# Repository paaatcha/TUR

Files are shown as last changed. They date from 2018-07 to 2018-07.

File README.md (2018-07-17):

# University Robotic Tournament

In this repository, you can find the codes and files of the [UFES robotic team](http://www.erus.ufes.br/) developed to the III University Robotic Tournament (TUR, in Portuguese), at Federal University of Uberlândia, Brazil. This project was developed by a team composed by me, Guilherme Artém and Vanderlei Vieira.

The tournament's rules are described in [rules.pd](https://github.com/paaatcha/TUR/blob/master/rules.pdf). In brief, the competition was a robot race in which the track race had a line that the robot must follow. In addition, there were extra challenges such as slopes, dark parts, crossroads, dangers turns, etc. The robot needed to be **autonomous** and complete the track race as fast as possible.

The robot structure was developed using the 3D software [openScad](http://www.openscad.org/). Next, this structure was printed in a 3D printer and used as the robot "body".

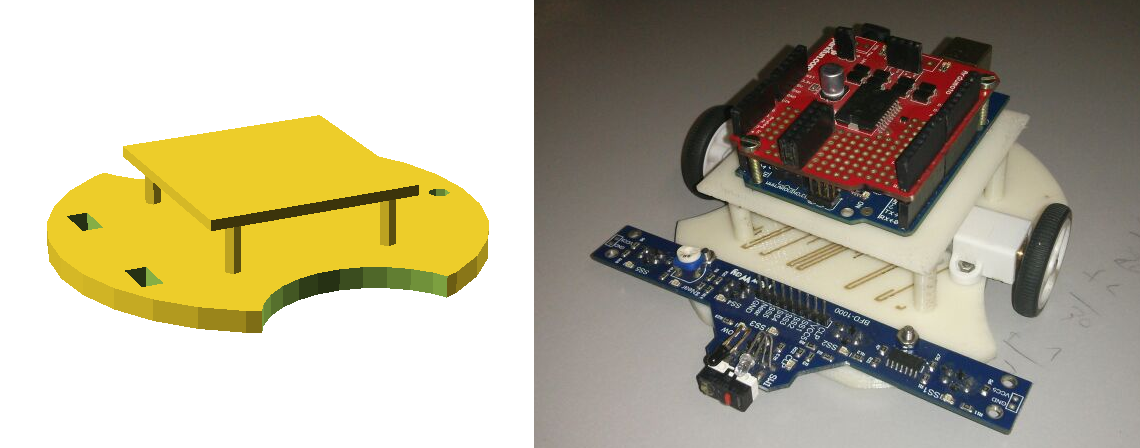
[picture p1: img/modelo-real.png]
Estrutra


The robot had 10 light sensors to track the line. We developed a PCB that you can find [here](http://github.com/paaatcha/TUR/eletronica). 

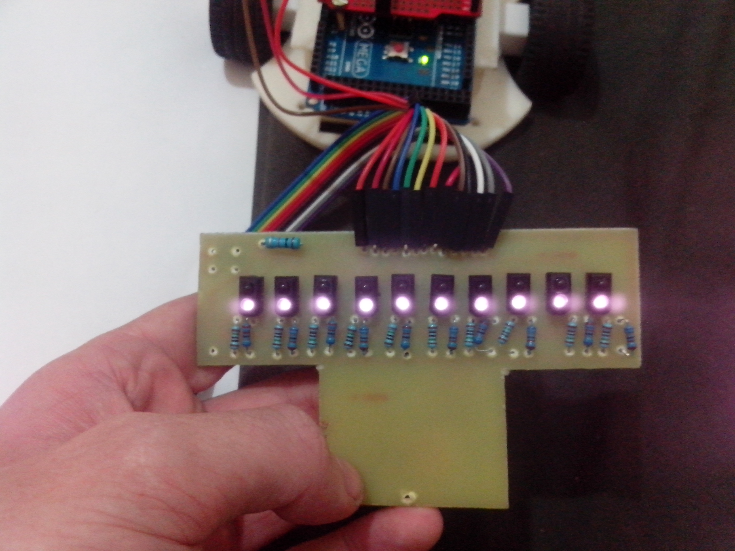
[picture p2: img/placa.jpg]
Sensores


The robot had an Arduino Mega, in which we implemented a PID control using C++. You can check out code in this [folder](https://github.com/paaatcha/TUR/tree/master/programacao).

Later, this robot became my undergraduate thesis, in which is described more detailed [here](http://github.com/paaatcha/projeto-graduacao).

Robot version 1: (you may note that in this version the robot has an Arduino UNO and the light sensors PCB wasn't the one pictured above)

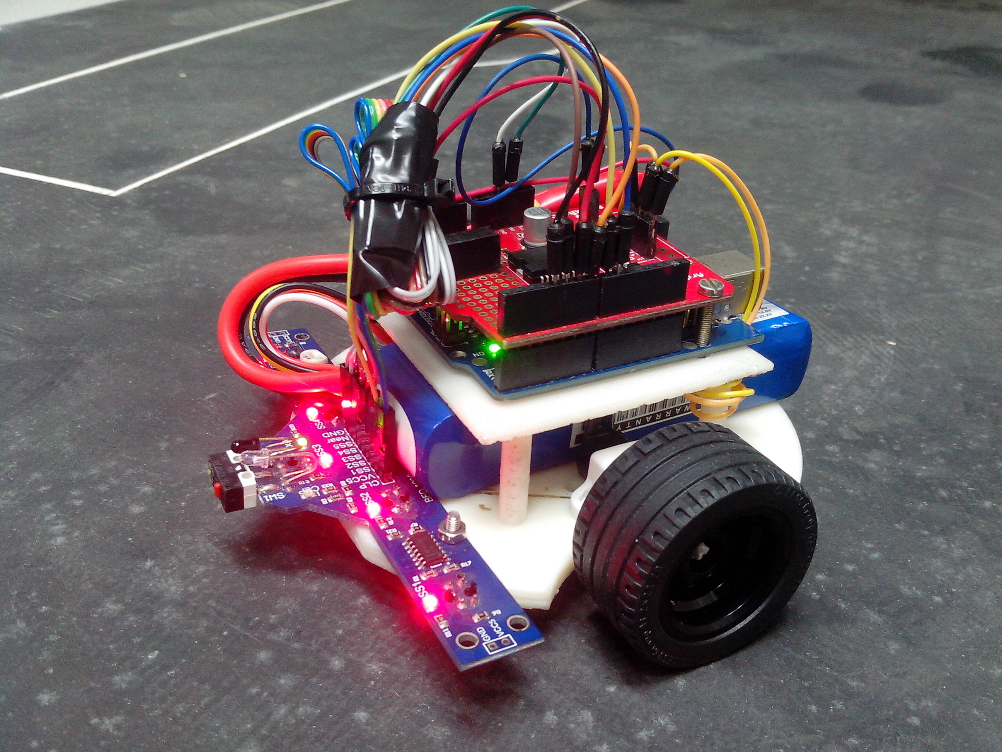
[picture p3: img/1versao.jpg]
Versao 1


Robot final version: (now it has the Arduino Mega and the developed PCB)
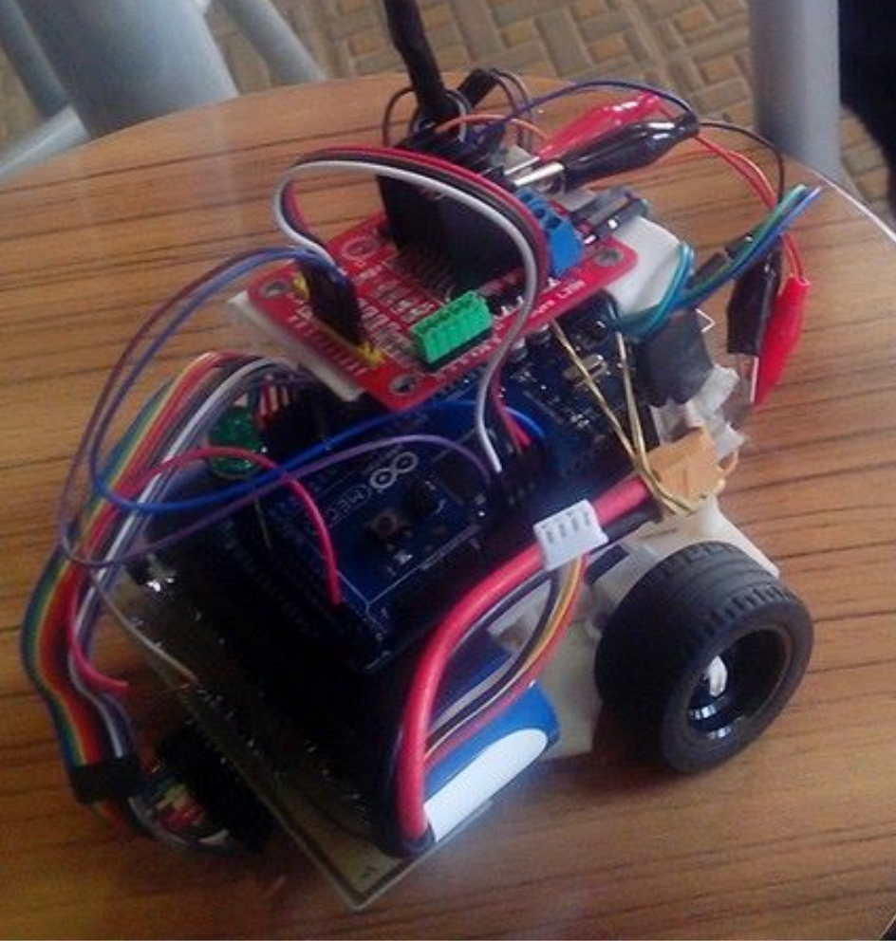
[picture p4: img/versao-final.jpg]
Versao final


Take look at the robot's performance on the official race track. It's very cool to see the PID working for the 90º turn.

IMAGE ALT TEXT HERE (https://www.youtube.com/watch?v=wrlccVcyYqc)

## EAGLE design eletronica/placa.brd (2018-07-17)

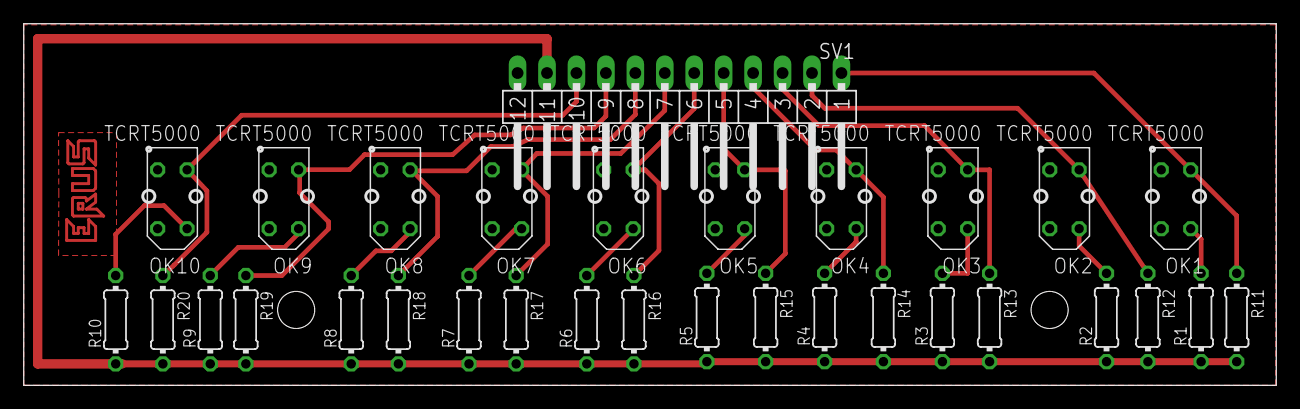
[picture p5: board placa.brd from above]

Board: 2 copper layers, 108.0 x 31.2 mm, 31 parts (0 on the bottom side), 22 nets.

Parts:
OK1, OK2, OK3, OK4, OK5, OK6, OK7, OK8, OK9, OK10: TCRT5000
R1, R2, R3, R4, R5, R6, R7, R8, R9, R10, R11, R12, R13, R14, R15, R16, R17, R18, R19, R20: 0204/7
SV1: MA12-1W

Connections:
5V: R1.1, R2.1, R3.1, R4.1, R5.1, R6.1, R7.1, R8.1, R9.1, R10.1, R11.2, R12.2, R13.2, R14.2, R15.2, R16.2, R17.2, R18.2, R19.2, R20.2, SV1.11
GND: OK1.E, OK1.KATODA, OK2.E, OK2.KATODA, OK3.E, OK3.KATODA, OK4.E, OK4.KATODA, OK5.E, OK5.KATODA, OK6.E, OK6.KATODA, OK7.E, OK7.KATODA, OK8.E, OK8.KATODA, OK9.E, OK9.KATODA, OK10.E, OK10.KATODA, SV1.12
unnamed: OK2.A, R2.2
unnamed: OK1.C, R11.1, SV1.1
unnamed: OK1.A, R1.2
unnamed: OK3.A, R3.2
unnamed: OK4.A, R4.2
unnamed: OK5.A, R5.2
unnamed: OK6.A, R6.2
unnamed: OK7.A, R7.2
unnamed: OK8.A, R8.2
unnamed: OK9.A, R9.2
unnamed: OK10.A, R10.2
unnamed: OK2.C, R12.1, SV1.2
unnamed: OK3.C, R13.1, SV1.3
unnamed: OK8.C, R18.1, SV1.8
unnamed: OK10.C, R20.1, SV1.10
unnamed: OK4.C, R14.1, SV1.4
unnamed: OK5.C, R15.1, SV1.5
unnamed: OK6.C, R16.1, SV1.6
unnamed: OK7.C, R17.1, SV1.7
unnamed: OK9.C, R19.1, SV1.9

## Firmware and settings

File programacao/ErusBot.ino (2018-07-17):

#include <Arduino.h>
#include "Pins.h"
#include "Motors.h"
#include "Sensors.h"
#include "PIDControl.h"
#include "Position.h"

#define STOP_TIME 13000

static unsigned long initialTime;
static unsigned long currentTime;
char colorLine = 'p';
int* sensors;
int pos=0; 
double signalControl;
static bool lastMoment = false;
int velocidadeMax = 25;

void setup(void)
{        
	Serial.begin(9600);
	setupSensors();
    setupMotors();
	setupPIDControl(0.029, 0.001, 0.13); //(kp=0.029,ki=0.001,kd=0.13) 
	pinMode(BUTTON, INPUT);
	sensors = readSensors(colorLine);
}

int checkInit(void)
{
	static int init = 0;
	if(!init)
	{
		if(digitalRead(BUTTON))
		{
			init = 1;
            delay(500);            
		}
	}	
	return init;
}

// retorna b se a linha for braca e p se a linha for preta
char checkColorLine (int *sensors){
	if (colorLine == 'p' && sensors[0] == HIGH && sensors[4] == HIGH){
		return 'b';
	}else if (colorLine == 'b' && sensors[0] == HIGH && sensors[4] == HIGH){
		return 'p';
	}else{
		return colorLine;
	}
}

void loop(void)
{       	
    if(!checkInit()){
		return;
	}

	//colorLine = checkColorLine (sensors);
	sensors = readSensors(colorLine);

	pos = getPosition(sensors);
        
    signalControl = round(getPIDControl(pos));

	Serial.print("signalControl: ");
	Serial.println(signalControl);
    
	// cotrole do robô
    /*if (signalControl > 0){ // estar tendendo para direita
		setMotor(1, velocidadeMax+signalControl, 1); // direita
		setMotor(0, velocidadeMax, 1); // esquerda	
	}else if (signalControl < 0){
		setMotor(1, velocidadeMax, 1); // direita
		setMotor(0, velocidadeMax-signalControl, 1); // esquerda		
	}else{
		setMotor(1, velocidadeMax, 1); // direita
		setMotor(0, velocidadeMax, 1); // esquerda		
	}*/
    
    
	// delay para adequar a taxa pra atualizar o sensor
	//delay (10);

	// para garantir a parada no local certo    
	/*if ( millis() - initialTime > STOP_TIME && lastMoment == true){
        setMotor(0,0,1);
        setMotor(1,0,1);
        
        return;
    }*/

    delay(1000);
}

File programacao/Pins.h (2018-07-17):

#ifndef PINS_H
#define PINS_H

// Digital pins

#define PWM_LEFT 3
#define PWM_RIGHT 11
#define DIR_LEFT 12
#define DIR_RIGHT 13

#define LIGHT_SENSOR_1 5
#define LIGHT_SENSOR_2 6
#define LIGHT_SENSOR_3 7
#define LIGHT_SENSOR_4 8
#define LIGHT_SENSOR_5 9

#define BUTTON 4


// Analog Pins

#define LED_GREEN 0
#define LED_BROWN 1
#define LED_BLUE 2

#endif

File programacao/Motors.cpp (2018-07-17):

#include <Arduino.h>
#include "Pins.h"
#include "Motors.h"

int motorPWMPins[2] = {PWM_LEFT, PWM_RIGHT};
int motorDirPins[2] = {DIR_LEFT, DIR_RIGHT};
int motorMAXPWM[2] = {220, 220}; // DO NOT CHANGE!!! YOU MAY DESTROY THE MOTORS!!!

void setupMotors(void)
{
	int i;
	for(i=0; i<2; i++)
	{
		pinMode(motorPWMPins[i], OUTPUT);
		pinMode(motorDirPins[i], OUTPUT);

		analogWrite(motorPWMPins[i], 0);
		digitalWrite(motorDirPins[i], HIGH);
	}
}


void setMotor(int motor, int velocity, uint8_t direction)
{
	
	// This protects the motor to the rated volgate. DO NOT CHANGE!!!
	if(velocity > motorMAXPWM[motor])
	{
		velocity = motorMAXPWM[motor];
	}
	
	if(velocity < 0)
	{
		velocity = 0;
	}

	if(direction)
	{
		digitalWrite(motorDirPins[motor], LOW);
	}
	else
	{
		digitalWrite(motorDirPins[motor], HIGH);
	}
		
	analogWrite(motorPWMPins[motor], velocity);
}

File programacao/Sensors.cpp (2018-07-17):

#include <Arduino.h>
#include "Pins.h"
#include "Sensors.h"

static int sensorsValues[6];

void setupSensors(void)
{
	pinMode(LIGHT_SENSOR_1, INPUT);
	pinMode(LIGHT_SENSOR_2, INPUT);
	pinMode(LIGHT_SENSOR_3, INPUT);
	pinMode(LIGHT_SENSOR_4, INPUT);
	pinMode(LIGHT_SENSOR_5, INPUT);
}

// Linha pode ser (p)reta ou (b)ranca.
int* readSensors(char linha)
{        
	//Lógica para linha preta em caminho branco; para linha branca em caminho preto retirar '1 -'        
    if (linha=='p'){        
	 	sensorsValues[4] = 1-digitalRead(LIGHT_SENSOR_1); 
		sensorsValues[3] = 1-digitalRead(LIGHT_SENSOR_2);
		sensorsValues[2] = 1-digitalRead(LIGHT_SENSOR_3);
    	sensorsValues[1] = 1-digitalRead(LIGHT_SENSOR_4);
		sensorsValues[0] = 1-digitalRead(LIGHT_SENSOR_5);
	}else if (linha=='b'){
	 	sensorsValues[4] = digitalRead(LIGHT_SENSOR_1); 
		sensorsValues[3] = digitalRead(LIGHT_SENSOR_2);
		sensorsValues[2] = digitalRead(LIGHT_SENSOR_3);
    	sensorsValues[1] = digitalRead(LIGHT_SENSOR_4);
		sensorsValues[0] = digitalRead(LIGHT_SENSOR_5);	
	}
	
	/*Serial.print("Sensors: ");
	int i;
	for (i=0; i<5; i++){
		Serial.print(sensorsValues[i]);
		if (i==4)
			Serial.println("");

		Serial.print(" | ");
	}

	delay(500);
	*/

	return &(sensorsValues[0]);
}
